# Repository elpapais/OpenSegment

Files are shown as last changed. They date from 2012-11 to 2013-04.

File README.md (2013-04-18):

OpenSegment Serial Display
==========================

[OpenSegment  
*OpenSegment Serial Display (Yellow) (COM-11645)*](https://www.sparkfun.com/products/11645)

OpenSegment is a ATmega328 based backpack for larger 7-segment displays. The ATmega receives data over digital interfaces (such as TWI, UART, SPI and buttons) and does all the PWM and upkeep of the display. 

Larger 7-segment displays pull more power than a microcontroller is able to drive directly. OpenSegment has 8 PNP and 4 NPN transistors in order to drive the segments at their maximum brightness.

**Features:**
* Standard FTDI connection
* Arduino Pro Mini @ 8MHz bootloader
* 5V functionality

This part was created in Eagle 6.3

Repository Contents
-------------------
* **/Hardware** - All Eagle design files and 3D files(.brd, .sch,)
* **/Production** - Test bed files and production panel files
* **Note:** Firmware is not included in this repo. Please see the [Serial7SegmentDisplay repo](https://github.com/sparkfun/Serial7SegmentDisplay) for the firmware. 

Product Versions
----------------
* [COM-11644](https://www.sparkfun.com/products/11644)- Red display
* [COM-11645](https://www.sparkfun.com/products/11645) - Yellow display
* [COM-11646](https://www.sparkfun.com/products/11646) - Green display
* [COM-11647](https://www.sparkfun.com/products/11647) - Blue display
* [COM-11648](https://www.sparkfun.com/products/11648) - White display

License Information
-------------------
The hardware is released under [Creative Commons Share-alike 3.0](http://creativecommons.org/licenses/by-sa/3.0/).

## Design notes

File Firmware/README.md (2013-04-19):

OpenSegment Serial Display Firmware
==========================

The firmware for OpenSegment is located over on the [Serial7Segment repo](https://github.com/sparkfun/Serial7SegmentDisplay/tree/master/firmware/Serial%207-Segment%20Display/Serial_7_Segment_Display_Firmware). We combined the firmware for both Serial7Segment and OpenSegment because it's the same code with different pin assignments (to make the PCB layout easier).

If there are any improvements or modifications you'd like to make to the firmware, please create an issue over on the Serial7Segment [issues page](https://github.com/sparkfun/Serial7SegmentDisplay/issues?state=open).

The firmware for Serial7Segment and OpenSegment are based on the [SevSeg](https://github.com/sparkfun/SevSeg) library for Arduino, written by SparkFun.

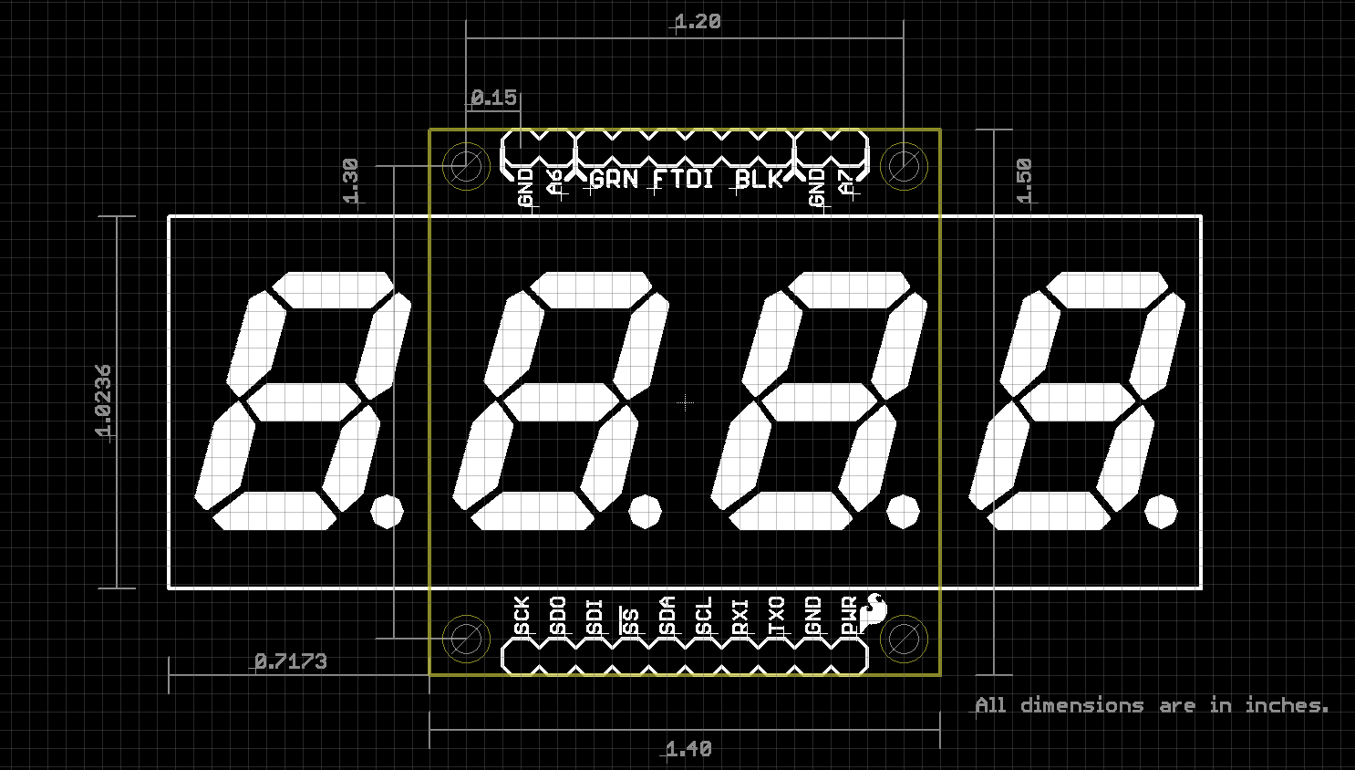
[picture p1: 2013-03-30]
Hardware/OpenSegment-Dimensions-v13.png

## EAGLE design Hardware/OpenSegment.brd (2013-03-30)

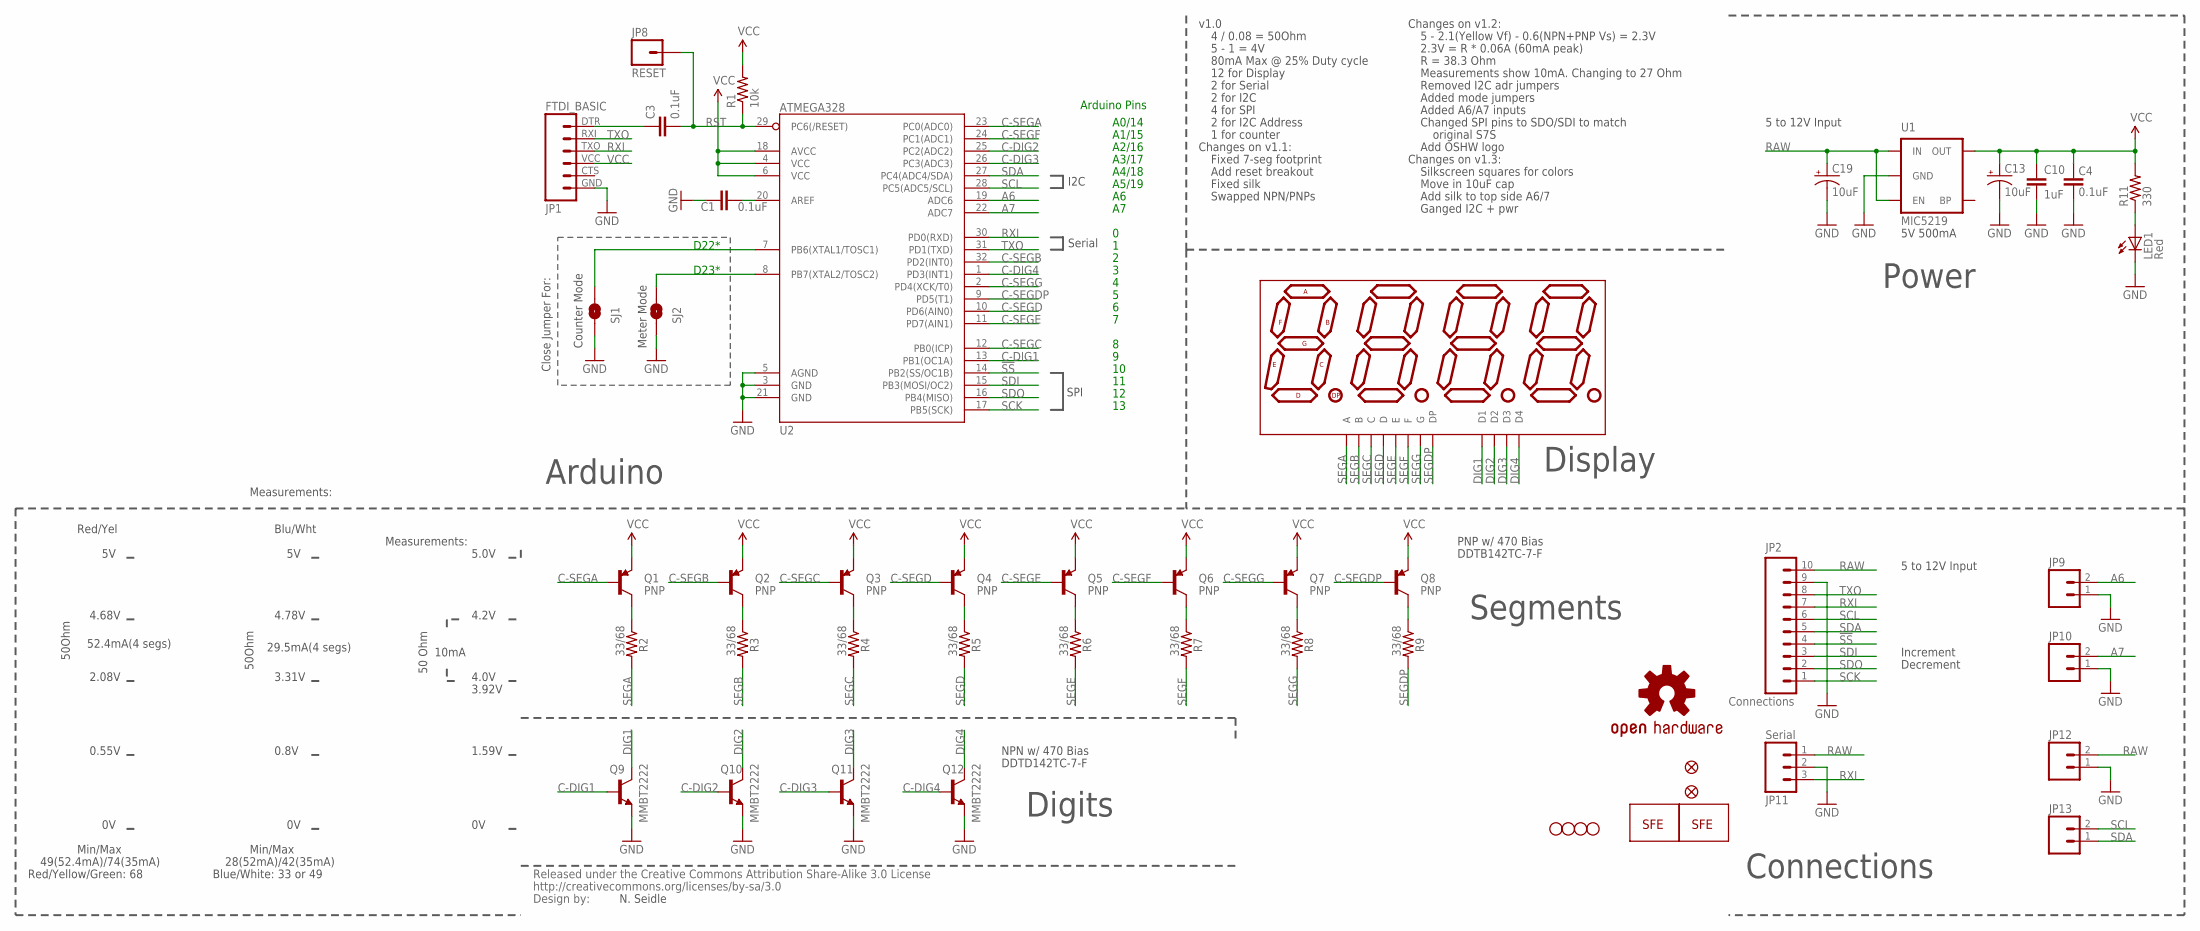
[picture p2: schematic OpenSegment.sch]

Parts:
C1, C3, C4: 0.1uF; 0402-CAP
C10: 1uF; 0402-CAP
C13, C19: 10uF; EIA3216
JP1: FTDI_BASIC
JP2: Connections; 1X10
JP3, JP4, JP5, JP6: STAND-OFF
JP7, JP14: FIDUCIALUFIDUCIAL; MICRO-FIDUCIAL
JP8: RESET; 1X01
JP9, JP10, JP12, JP13: M02PTH; 1X02
JP11: Serial; JST-3-PTH
LED1: Red; LED-0603
Q1, Q2, Q3, Q4, Q5, Q6, Q7, Q8: PNP; SOT23-3
Q9, Q10, Q11, Q12: MMBT2222; SOT23-3
R1: 10k; 0402-RES
R2, R3, R4, R5, R6, R7, R8, R9: 33/68; 0402-RES
R11: 330; 0402-RES
SJ1, SJ2: Counter Ctl; SJ_2S-NO
U1: MIC5219; SOT23-5
U2: ATMEGA328; TQFP32-08
U3: 7-SEGMENT-4DIGIT-COUNTERPTH; 7-SEGMENT-4DIGIT-COUNTER
U$2: LOGO-SFESK; SFE-LOGO-FLAME
U$3: CREATIVE_COMMONS
U$4: OSHW-LOGOS; OSHW-LOGO-S
U$7: LOGO-SFENW2; SFE-NEW-WEB

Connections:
!SS: JP2.4, U2.14 (PB2(SS/OC1B))
A6: JP9.2, U2.19 (ADC6)
A7: JP10.2, U2.22 (ADC7)
ANALOG: SJ2.1, U2.8 (PB7(XTAL2/TOSC2))
C-DIG1: Q9.1 (B), U2.13 (PB1(OC1A))
C-DIG2: Q10.1 (B), U2.25 (PC2(ADC2))
C-DIG3: Q11.1 (B), U2.26 (PC3(ADC3))
C-DIG4: Q12.1 (B), U2.1 (PD3(INT1))
C-SEGA: Q1.1 (B), U2.23 (PC0(ADC0))
C-SEGB: Q2.1 (B), U2.32 (PD2(INT0))
C-SEGC: Q3.1 (B), U2.12 (PB0(ICP))
C-SEGD: Q4.1 (B), U2.10 (PD6(AIN0))
C-SEGDP: Q8.1 (B), U2.9 (PD5(T1))
C-SEGE: Q5.1 (B), U2.11 (PD7(AIN1))
C-SEGF: Q6.1 (B), U2.24 (PC1(ADC1))
C-SEGG: Q7.1 (B), U2.2 (PD4(XCK/T0))
COUNTER: SJ1.1, U2.7 (PB6(XTAL1/TOSC1))
DIG1: Q9.3 (C), U3.12 (D1)
DIG2: Q10.3 (C), U3.9 (D2)
DIG3: Q11.3 (C), U3.8 (D3)
DIG4: Q12.3 (C), U3.6 (D4)
GND: C1.1, C4.1, C10.2, C13.C (-), C19.C (-), JP1.GND (6), JP2.9, JP9.1, JP10.1, JP11.2, JP12.1, LED1.C, Q9.2 (E), Q10.2 (E), Q11.2 (E), Q12.2 (E), SJ1.2, SJ2.2, U1.2 (GND), U2.3 (GND), U2.5 (AGND), U2.21 (GND)
unnamed: Q1.3 (C), R2.1
unnamed: C3.1, JP1.DTR (1)
unnamed: Q2.3 (C), R3.1
unnamed: Q3.3 (C), R4.1
unnamed: Q4.3 (C), R5.1
unnamed: Q5.3 (C), R6.1
unnamed: Q6.3 (C), R7.1
unnamed: Q7.3 (C), R8.1
unnamed: Q8.3 (C), R9.1
unnamed: C1.2, U2.20 (AREF)
unnamed: LED1.A, R11.1
RAW: C19.A (+), JP2.10, JP11.1, JP12.2, U1.1 (IN), U1.3 (EN)
RST: C3.2, JP8.1, R1.1, U2.29 (PC6(/RESET))
RXI: JP1.TXO (3), JP2.7, JP11.3, U2.30 (PD0(RXD))
SCK: JP2.1, U2.17 (PB5(SCK))
SCL: JP2.6, JP13.2, U2.28 (PC5(ADC5/SCL))
SDA: JP2.5, JP13.1, U2.27 (PC4(ADC4/SDA))
SDI: JP2.3, U2.15 (PB3(MOSI/OC2))
SDO: JP2.2, U2.16 (PB4(MISO))
SEGA: R2.2, U3.11 (A)
SEGB: R3.2, U3.7 (B)
SEGC: R4.2, U3.4 (C)
SEGD: R5.2, U3.2 (D)
SEGDP: R9.2, U3.3 (DP)
SEGE: R6.2, U3.1 (E)
SEGF: R7.2, U3.10 (F)
SEGG: R8.2, U3.5 (G)
TXO: JP1.RXI (2), JP2.8, U2.31 (PD1(TXD))
VCC: C4.2, C10.1, C13.A (+), JP1.VCC (4), Q1.2 (E), Q2.2 (E), Q3.2 (E), Q4.2 (E), Q5.2 (E), Q6.2 (E), Q7.2 (E), Q8.2 (E), R1.2, R11.2, U1.5 (OUT), U2.4 (VCC), U2.6 (VCC), U2.18 (AVCC)

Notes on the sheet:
N. Seidle
A0/14
A1/15
A2/16
A3/17
A4/18
A5/19
Arduino Pins
Changes on v1.1:
5V 500mA
5 - 1 = 4V
80mA Max @ 25% Duty cycle
4 / 0.08 = 50Ohm
SPI
12 for Display
1 for counter
2 for I2C
4 for SPI
2 for Serial
v1.0
2 for I2C Address
Serial
I2C
Counter Mode
Arduino
Display
Segments
Digits
Connections
Power
Fixed 7-seg footprint
Add reset breakout
Fixed silk
Swapped NPN/PNPs
D22*
D23*
5 - 2.1(Yellow Vf) - 0.6(NPN+PNP Vs) = 2.3V
2.3V = R * 0.06A (60mA peak)
Changes on v1.2:
4.2V

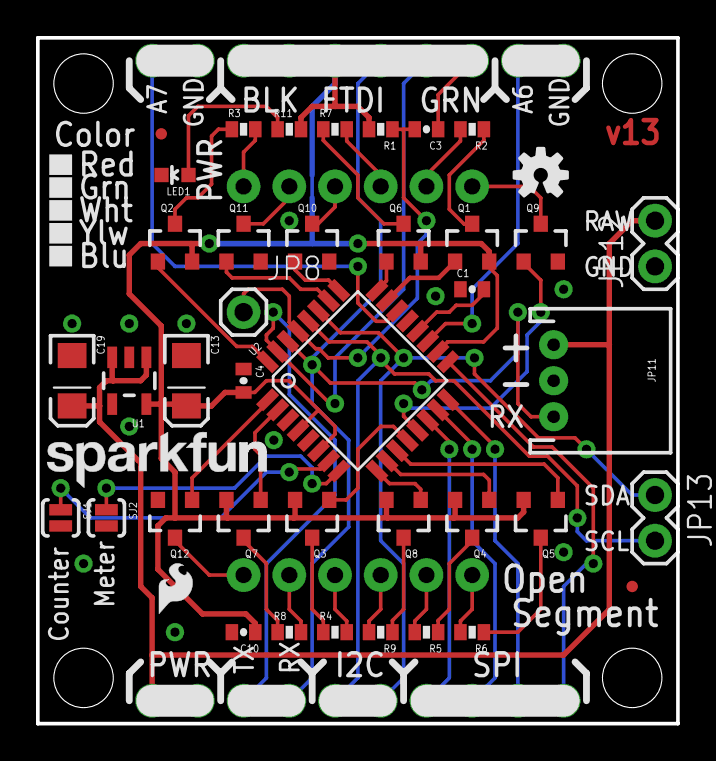
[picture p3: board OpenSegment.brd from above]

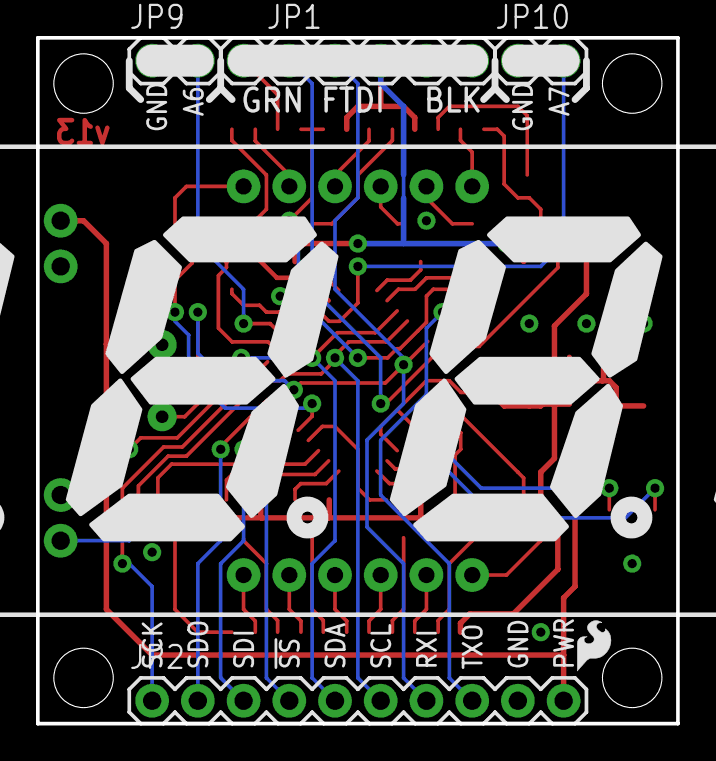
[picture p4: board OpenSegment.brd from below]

Board: 2 copper layers, 35.6 x 38.1 mm, 53 parts (6 on the bottom side), 51 nets.

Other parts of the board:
U$1: LOGO-SFESK; SFE-LOGO-FLAME

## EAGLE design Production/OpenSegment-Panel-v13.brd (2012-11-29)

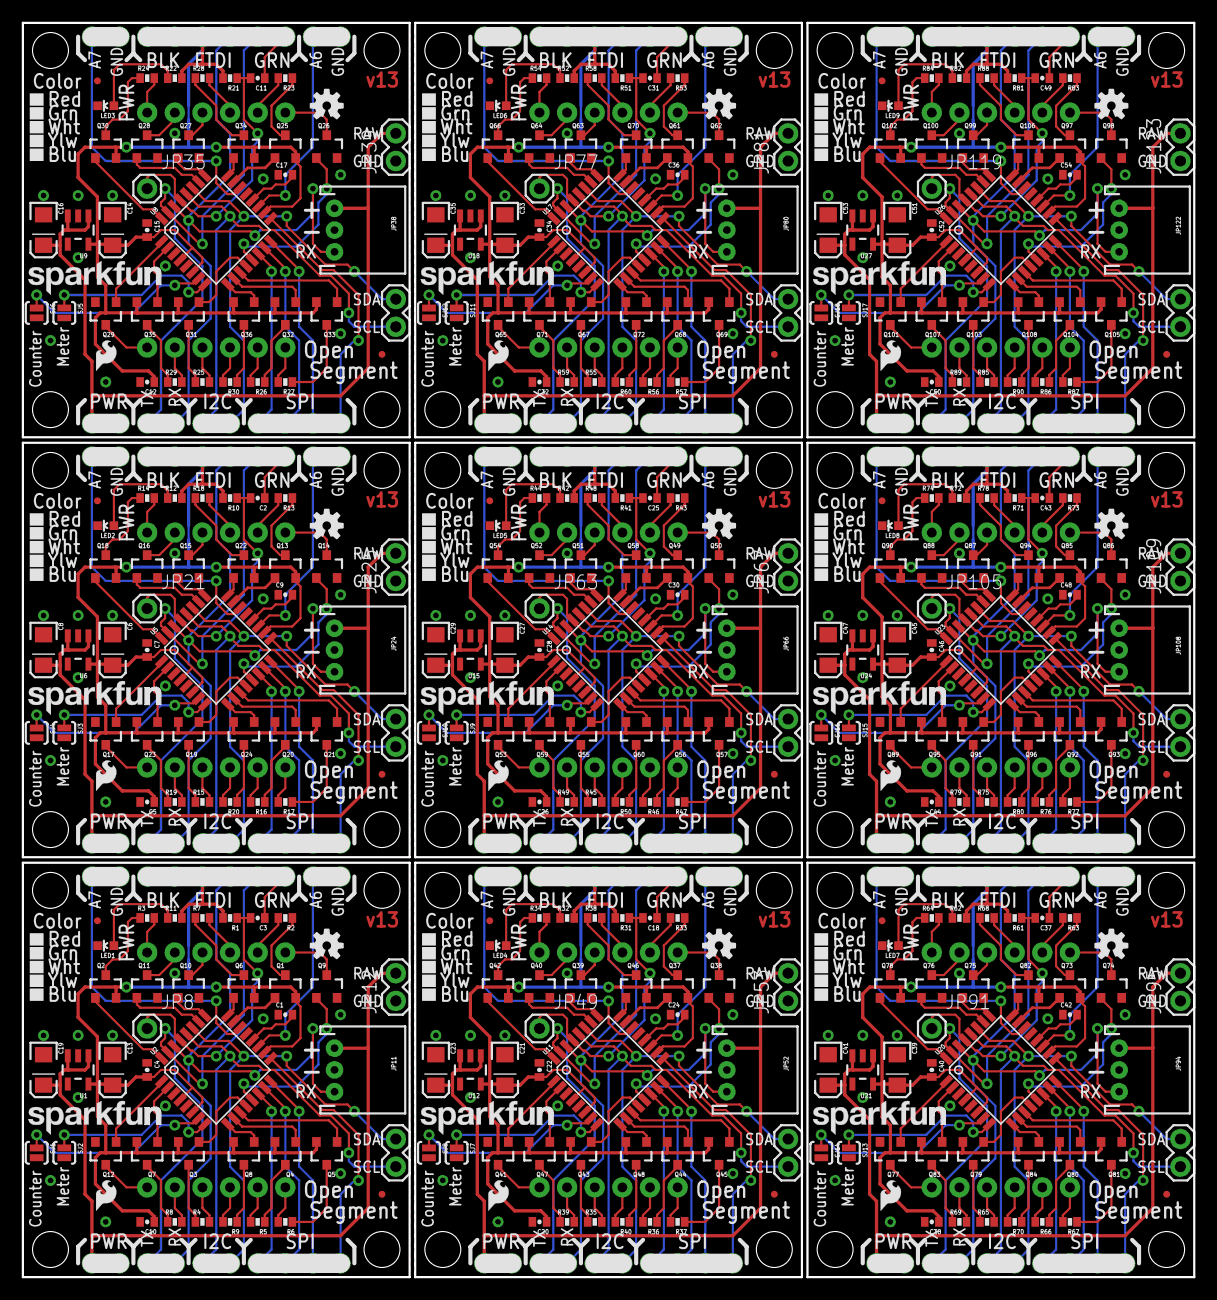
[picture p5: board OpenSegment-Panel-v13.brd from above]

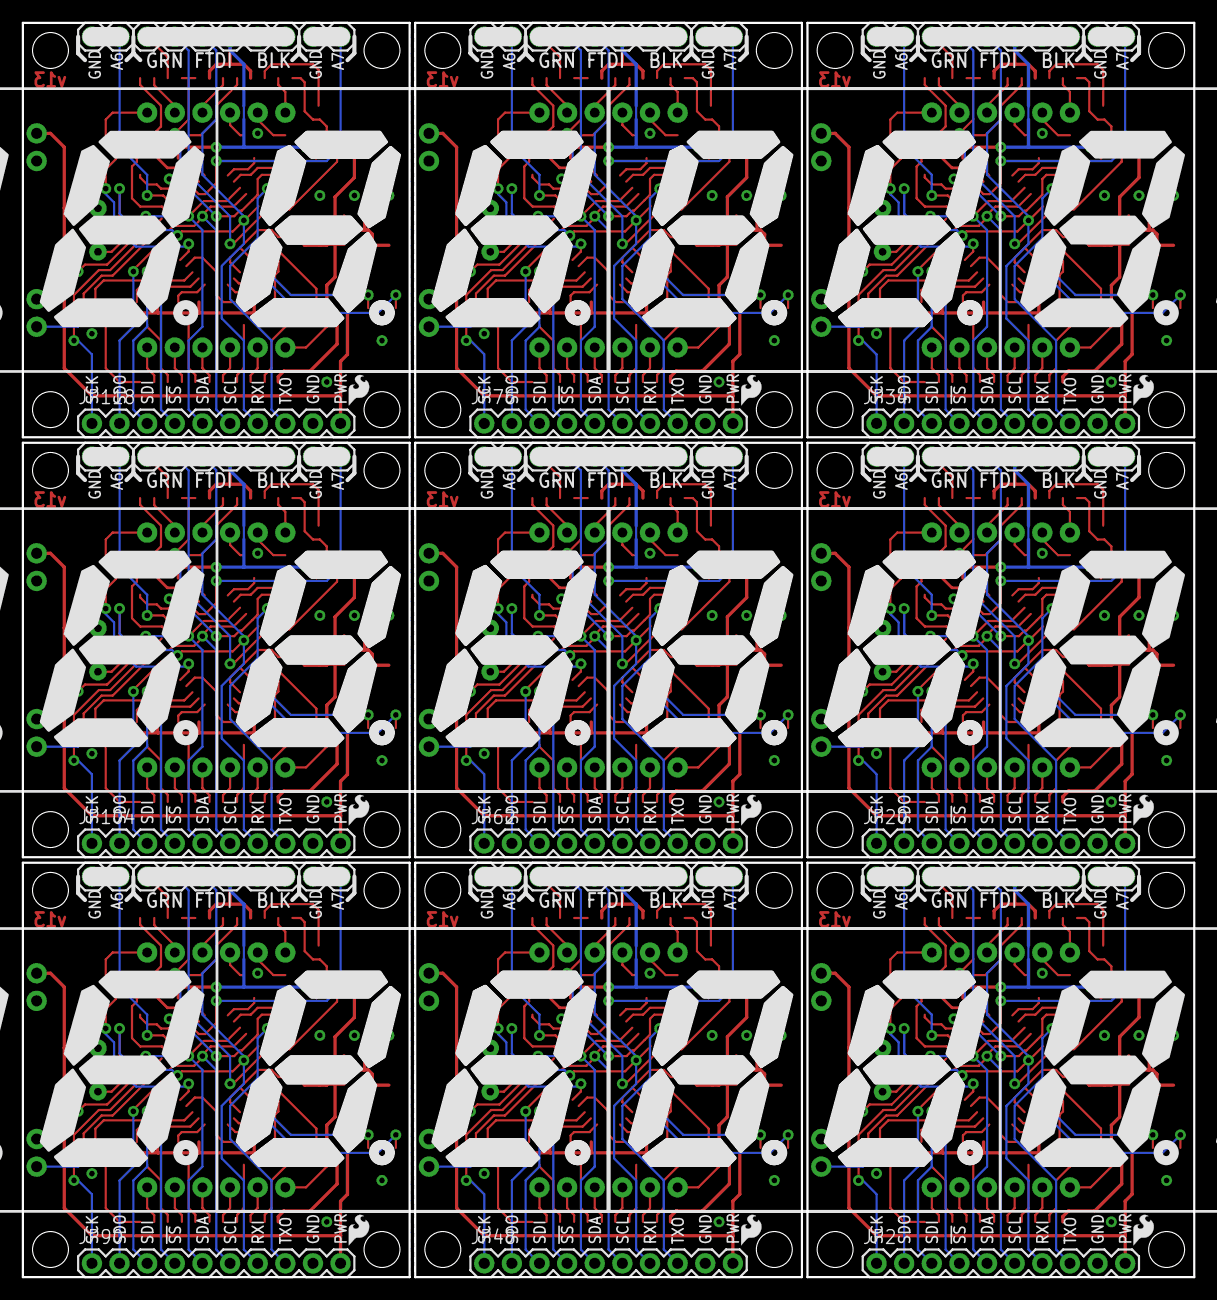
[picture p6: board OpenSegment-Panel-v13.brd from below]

Board: 2 copper layers, 107.7 x 115.3 mm, 468 parts (54 on the bottom side), 459 nets.

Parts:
C1, C2, C3, C4, C7, C9, C11, C15, C17, C18, C22, C24, C25, C28, C30, C31, C34, C36, C37, C40, C42, C43, C46, C48, C49, C52, C54: 0.1uF; 0402-CAP
C5, C10, C12, C20, C26, C32, C38, C44, C50: 1uF; 0402-CAP
C6, C8, C13, C14, C16, C19, C21, C23, C27, C29, C33, C35, C39, C41, C45, C47, C51, C53: 10uF; EIA3216
JP1, JP15, JP29, JP43, JP57, JP71, JP85, JP99, JP113: FTDI_BASIC
JP2, JP20, JP34, JP48, JP62, JP76, JP90, JP104, JP118: Connections; 1X10
JP3, JP4, JP5, JP6, JP16, JP17, JP18, JP19, JP30, JP31, JP32, JP33, JP44, JP45, JP46, JP47, JP58, JP59, JP60, JP61, JP72, JP73, JP74, JP75, JP86, JP87, JP88, JP89, JP100, JP101, JP102, JP103, JP114, JP115, JP116, JP117: STAND-OFF
JP7, JP14, JP27, JP28, JP41, JP42, JP55, JP56, JP69, JP70, JP83, JP84, JP97, JP98, JP111, JP112, JP125, JP126: FIDUCIALUFIDUCIAL; MICRO-FIDUCIAL
JP8, JP21, JP35, JP49, JP63, JP77, JP91, JP105, JP119: RESET; 1X01
JP9, JP10, JP12, JP13, JP22, JP23, JP25, JP26, JP36, JP37, JP39, JP40, JP50, JP51, JP53, JP54, JP64, JP65, JP67, JP68, JP78, JP79, JP81, JP82, JP92, JP93, JP95, JP96, JP106, JP107, JP109, JP110, JP120, JP121, JP123, JP124: 1X02
JP11, JP24, JP38, JP52, JP66, JP80, JP94, JP108, JP122: Serial; JST-3-PTH
LED1, LED2, LED3, LED4, LED5, LED6, LED7, LED8, LED9: Red; LED-0603
Q1, Q2, Q3, Q4, Q5, Q6, Q7, Q8, Q13, Q18, Q19, Q20, Q21, Q22, Q23, Q24, Q25, Q30, Q31, Q32, Q33, Q34, Q35, Q36, Q37, Q42, Q43, Q44, Q45, Q46, Q47, Q48, Q49, Q54, Q55, Q56, Q57, Q58, Q59, Q60, Q61, Q66, Q67, Q68, Q69, Q70, Q71, Q72, Q73, Q78, Q79, Q80, Q81, Q82, Q83, Q84, Q85, Q90, Q91, Q92, Q93, Q94, Q95, Q96, Q97, Q102, Q103, Q104, Q105, Q106, Q107, Q108: PNP; SOT23-3
Q9, Q10, Q11, Q12, Q14, Q15, Q16, Q17, Q26, Q27, Q28, Q29, Q38, Q39, Q40, Q41, Q50, Q51, Q52, Q53, Q62, Q63, Q64, Q65, Q74, Q75, Q76, Q77, Q86, Q87, Q88, Q89, Q98, Q99, Q100, Q101: MMBT2222; SOT23-3
R1, R10, R21, R31, R41, R51, R61, R71, R81: 10k; 0402-RES
R2, R3, R4, R5, R6, R7, R8, R9, R13, R14, R15, R16, R17, R18, R19, R20, R23, R24, R25, R26, R27, R28, R29, R30, R33, R34, R35, R36, R37, R38, R39, R40, R43, R44, R45, R46, R47, R48, R49, R50, R53, R54, R55, R56, R57, R58, R59, R60, R63, R64, R65, R66, R67, R68, R69, R70, R73, R74, R75, R76, R77, R78, R79, R80, R83, R84, R85, R86, R87, R88, R89, R90: 27; 0402-RES
R11, R12, R22, R32, R42, R52, R62, R72, R82: 330; 0402-RES
SJ1, SJ2, SJ3, SJ4, SJ5, SJ6, SJ7, SJ8, SJ9, SJ10, SJ11, SJ12, SJ13, SJ14, SJ15, SJ16, SJ17, SJ18: Counter Ctl; SJ_2S-NO
U1, U6, U9, U12, U15, U18, U21, U24, U27: MIC5219; SOT23-5
U2, U5, U8, U11, U14, U17, U20, U23, U26: ATMEGA328; TQFP32-08
U3, U4, U7, U10, U13, U16, U19, U22, U25: 7-SEGMENT-4DIGIT-COUNTERPTH; 7-SEGMENT-4DIGIT-COUNTER
U$1, U$2, U$5, U$6, U$10, U$11, U$14, U$15, U$18, U$19, U$22, U$23, U$26, U$27, U$30, U$31, U$34, U$35: LOGO-SFESK; SFE-LOGO-FLAME
U$3, U$7, U$9, U$13, U$17, U$21, U$25, U$29, U$33: LOGO-SFENW2; SFE-NEW-WEB
U$4, U$8, U$12, U$16, U$20, U$24, U$28, U$32, U$36: OSHW-LOGOS; OSHW-LOGO-S

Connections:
!SS: JP2.4, U2.14
!SS1: JP20.4, U5.14
!SS2: JP34.4, U8.14
!SS3: JP48.4, U11.14
!SS4: JP62.4, U14.14
!SS5: JP76.4, U17.14
!SS6: JP90.4, U20.14
!SS7: JP104.4, U23.14
!SS8: JP118.4, U26.14
A1: JP22.2, U5.19
A2: JP23.2, U5.22
A3: JP36.2, U8.19
A4: JP37.2, U8.22
A5: JP50.2, U11.19
A6: JP9.2, U2.19
A7: JP10.2, U2.22
A8: JP51.2, U11.22
A9: JP64.2, U14.19
A10: JP65.2, U14.22
A11: JP78.2, U17.19
A12: JP79.2, U17.22
A13: JP92.2, U20.19
A14: JP93.2, U20.22
A15: JP106.2, U23.19
A16: JP107.2, U23.22
A17: JP120.2, U26.19
A18: JP121.2, U26.22
ANALOG: SJ2.1, U2.8
ANALOG1: SJ3.1, U5.8
ANALOG2: SJ5.1, U8.8
ANALOG3: SJ7.1, U11.8
ANALOG4: SJ9.1, U14.8
ANALOG5: SJ11.1, U17.8
ANALOG6: SJ13.1, U20.8
ANALOG7: SJ15.1, U23.8
ANALOG8: SJ17.1, U26.8
C-DIG1: Q9.1, U2.13
C-DIG2: Q10.1, U2.25
C-DIG3: Q11.1, U2.26
C-DIG4: Q12.1, U2.1
C-DIG5: Q14.1, U5.13
C-DIG6: Q15.1, U5.25
C-DIG7: Q16.1, U5.26
C-DIG8: Q17.1, U5.1
C-DIG9: Q26.1, U8.13
C-DIG10: Q27.1, U8.25
C-DIG11: Q28.1, U8.26
C-DIG12: Q29.1, U8.1
C-DIG13: Q38.1, U11.13
C-DIG14: Q39.1, U11.25
C-DIG15: Q40.1, U11.26
C-DIG16: Q41.1, U11.1
C-DIG17: Q50.1, U14.13
C-DIG18: Q51.1, U14.25
C-DIG19: Q52.1, U14.26
C-DIG20: Q53.1, U14.1
C-DIG21: Q62.1, U17.13
C-DIG22: Q63.1, U17.25
C-DIG23: Q64.1, U17.26
C-DIG24: Q65.1, U17.1
C-DIG25: Q74.1, U20.13
C-DIG26: Q75.1, U20.25
C-DIG27: Q76.1, U20.26
C-DIG28: Q77.1, U20.1
C-DIG29: Q86.1, U23.13
C-DIG30: Q87.1, U23.25
C-DIG31: Q88.1, U23.26
C-DIG32: Q89.1, U23.1
C-DIG33: Q98.1, U26.13
C-DIG34: Q99.1, U26.25
C-DIG35: Q100.1, U26.26
C-DIG36: Q101.1, U26.1
C-SEGA: Q1.1, U2.23
C-SEGA1: Q13.1, U5.23
C-SEGA2: Q25.1, U8.23
C-SEGA3: Q37.1, U11.23
C-SEGA4: Q49.1, U14.23
C-SEGA5: Q61.1, U17.23
C-SEGA6: Q73.1, U20.23
C-SEGA7: Q85.1, U23.23
C-SEGA8: Q97.1, U26.23
C-SEGB: Q2.1, U2.32
C-SEGB1: Q18.1, U5.32
C-SEGB2: Q30.1, U8.32
C-SEGB3: Q42.1, U11.32
C-SEGB4: Q54.1, U14.32
C-SEGB5: Q66.1, U17.32
C-SEGB6: Q78.1, U20.32
C-SEGB7: Q90.1, U23.32
C-SEGB8: Q102.1, U26.32
C-SEGC: Q3.1, U2.12
C-SEGC1: Q19.1, U5.12
C-SEGC2: Q31.1, U8.12
C-SEGC3: Q43.1, U11.12
C-SEGC4: Q55.1, U14.12
C-SEGC5: Q67.1, U17.12
C-SEGC6: Q79.1, U20.12
C-SEGC7: Q91.1, U23.12
C-SEGC8: Q103.1, U26.12
C-SEGD: Q4.1, U2.10
C-SEGD1: Q20.1, U5.10
C-SEGD2: Q32.1, U8.10
C-SEGD3: Q44.1, U11.10
C-SEGD4: Q56.1, U14.10
C-SEGD5: Q68.1, U17.10
C-SEGD6: Q80.1, U20.10
C-SEGD7: Q92.1, U23.10
C-SEGD8: Q104.1, U26.10
C-SEGDP: Q8.1, U2.9
C-SEGDP1: Q24.1, U5.9
C-SEGDP2: Q36.1, U8.9
C-SEGDP3: Q48.1, U11.9
C-SEGDP4: Q60.1, U14.9
C-SEGDP5: Q72.1, U17.9
C-SEGDP6: Q84.1, U20.9
C-SEGDP7: Q96.1, U23.9
C-SEGDP8: Q108.1, U26.9
C-SEGE: Q5.1, U2.11
C-SEGE1: Q21.1, U5.11
C-SEGE2: Q33.1, U8.11
C-SEGE3: Q45.1, U11.11
C-SEGE4: Q57.1, U14.11
C-SEGE5: Q69.1, U17.11
C-SEGE6: Q81.1, U20.11
C-SEGE7: Q93.1, U23.11
C-SEGE8: Q105.1, U26.11
C-SEGF: Q6.1, U2.24
C-SEGF1: Q22.1, U5.24
C-SEGF2: Q34.1, U8.24
C-SEGF3: Q46.1, U11.24
C-SEGF4: Q58.1, U14.24
C-SEGF5: Q70.1, U17.24
C-SEGF6: Q82.1, U20.24
C-SEGF7: Q94.1, U23.24
C-SEGF8: Q106.1, U26.24
C-SEGG: Q7.1, U2.2
C-SEGG1: Q23.1, U5.2
C-SEGG2: Q35.1, U8.2
C-SEGG3: Q47.1, U11.2
C-SEGG4: Q59.1, U14.2
C-SEGG5: Q71.1, U17.2
C-SEGG6: Q83.1, U20.2
C-SEGG7: Q95.1, U23.2
C-SEGG8: Q107.1, U26.2
COUNTER: SJ1.1, U2.7
COUNTER1: SJ4.1, U5.7
COUNTER2: SJ6.1, U8.7
COUNTER3: SJ8.1, U11.7
COUNTER4: SJ10.1, U14.7
COUNTER5: SJ12.1, U17.7
COUNTER6: SJ14.1, U20.7
COUNTER7: SJ16.1, U23.7
COUNTER8: SJ18.1, U26.7
DIG1: Q9.3, U3.12
DIG2: Q10.3, U3.9
DIG3: Q11.3, U3.8
DIG4: Q12.3, U3.6
DIG5: Q14.3, U4.12
DIG6: Q15.3, U4.9
DIG7: Q16.3, U4.8
DIG8: Q17.3, U4.6
DIG9: Q26.3, U7.12
DIG10: Q27.3, U7.9
DIG11: Q28.3, U7.8
DIG12: Q29.3, U7.6
DIG13: Q38.3, U10.12
DIG14: Q39.3, U10.9
DIG15: Q40.3, U10.8
DIG16: Q41.3, U10.6
DIG17: Q50.3, U13.12
DIG18: Q51.3, U13.9
DIG19: Q52.3, U13.8
DIG20: Q53.3, U13.6
DIG21: Q62.3, U16.12
DIG22: Q63.3, U16.9
DIG23: Q64.3, U16.8
DIG24: Q65.3, U16.6
DIG25: Q74.3, U19.12
DIG26: Q75.3, U19.9
DIG27: Q76.3, U19.8
DIG28: Q77.3, U19.6
DIG29: Q86.3, U22.12
DIG30: Q87.3, U22.9
DIG31: Q88.3, U22.8
DIG32: Q89.3, U22.6
DIG33: Q98.3, U25.12
DIG34: Q99.3, U25.9
DIG35: Q100.3, U25.8
DIG36: Q101.3, U25.6
GND: C1.1, C4.1, C10.2, C13.C, C19.C, JP1.GND, JP2.9, JP9.1, JP10.1, JP11.2, JP12.1, LED1.C, Q9.2, Q10.2, Q11.2, Q12.2, SJ1.2, SJ2.2, U1.2, U2.3, U2.5, U2.21
GND1: C5.2, C6.C, C7.1, C8.C, C9.1, JP15.GND, JP20.9, JP22.1, JP23.1, JP24.2, JP25.1, LED2.C, Q14.2, Q15.2, Q16.2, Q17.2, SJ3.2, SJ4.2, U5.3, U5.5, U5.21, U6.2
GND2: C12.2, C14.C, C15.1, C16.C, C17.1, JP29.GND, JP34.9, JP36.1, JP37.1, JP38.2, JP39.1, LED3.C, Q26.2, Q27.2, Q28.2, Q29.2, SJ5.2, SJ6.2, U8.3, U8.5, U8.21, U9.2
GND3: C20.2, C21.C, C22.1, C23.C, C24.1, JP43.GND, JP48.9, JP50.1, JP51.1, JP52.2, JP53.1, LED4.C, Q38.2, Q39.2, Q40.2, Q41.2, SJ7.2, SJ8.2, U11.3, U11.5, U11.21, U12.2
GND4: C26.2, C27.C, C28.1, C29.C, C30.1, JP57.GND, JP62.9, JP64.1, JP65.1, JP66.2, JP67.1, LED5.C, Q50.2, Q51.2, Q52.2, Q53.2, SJ9.2, SJ10.2, U14.3, U14.5, U14.21, U15.2
GND5: C32.2, C33.C, C34.1, C35.C, C36.1, JP71.GND, JP76.9, JP78.1, JP79.1, JP80.2, JP81.1, LED6.C, Q62.2, Q63.2, Q64.2, Q65.2, SJ11.2, SJ12.2, U17.3, U17.5, U17.21, U18.2
GND6: C38.2, C39.C, C40.1, C41.C, C42.1, JP85.GND, JP90.9, JP92.1, JP93.1, JP94.2, JP95.1, LED7.C, Q74.2, Q75.2, Q76.2, Q77.2, SJ13.2, SJ14.2, U20.3, U20.5, U20.21, U21.2
GND7: C44.2, C45.C, C46.1, C47.C, C48.1, JP99.GND, JP104.9, JP106.1, JP107.1, JP108.2, JP109.1, LED8.C, Q86.2, Q87.2, Q88.2, Q89.2, SJ15.2, SJ16.2, U23.3, U23.5, U23.21, U24.2
GND8: C50.2, C51.C, C52.1, C53.C, C54.1, JP113.GND, JP118.9, JP120.1, JP121.1, JP122.2, JP123.1, LED9.C, Q98.2, Q99.2, Q100.2, Q101.2, SJ17.2, SJ18.2, U26.3, U26.5, U26.21, U27.2
unnamed: Q1.3, R2.1
unnamed: C2.1, JP15.DTR
unnamed: C3.1, JP1.DTR
unnamed: Q2.3, R3.1
unnamed: Q3.3, R4.1
unnamed: Q4.3, R5.1
unnamed: Q5.3, R6.1
unnamed: Q6.3, R7.1
unnamed: Q7.3, R8.1
unnamed: Q8.3, R9.1
unnamed: C1.2, U2.20
unnamed: LED2.A, R12.1
unnamed: Q13.3, R13.1
unnamed: Q18.3, R14.1
unnamed: Q19.3, R15.1
unnamed: Q20.3, R16.1
unnamed: Q21.3, R17.1
unnamed: Q22.3, R18.1
unnamed: Q23.3, R19.1
unnamed: Q24.3, R20.1
unnamed: C9.2, U5.20
unnamed: C11.1, JP29.DTR
unnamed: LED3.A, R22.1
unnamed: Q25.3, R23.1
unnamed: Q30.3, R24.1
unnamed: Q31.3, R25.1
unnamed: Q32.3, R26.1
unnamed: Q33.3, R27.1
unnamed: Q34.3, R28.1
unnamed: Q35.3, R29.1
unnamed: Q36.3, R30.1
unnamed: C17.2, U8.20
unnamed: C18.1, JP43.DTR
unnamed: LED4.A, R32.1
unnamed: Q37.3, R33.1
unnamed: Q42.3, R34.1
unnamed: Q43.3, R35.1
unnamed: LED1.A, R11.1
unnamed: Q44.3, R36.1
unnamed: Q45.3, R37.1
unnamed: Q46.3, R38.1
unnamed: Q47.3, R39.1
unnamed: Q48.3, R40.1
unnamed: C24.2, U11.20
unnamed: C25.1, JP57.DTR
unnamed: LED5.A, R42.1
unnamed: Q49.3, R43.1
unnamed: Q54.3, R44.1
unnamed: Q55.3, R45.1
unnamed: Q56.3, R46.1
unnamed: Q57.3, R47.1
unnamed: Q58.3, R48.1
unnamed: Q59.3, R49.1
unnamed: Q60.3, R50.1
unnamed: C30.2, U14.20
unnamed: C31.1, JP71.DTR
unnamed: LED6.A, R52.1
unnamed: Q61.3, R53.1
unnamed: Q66.3, R54.1
unnamed: Q67.3, R55.1
unnamed: Q68.3, R56.1
unnamed: Q69.3, R57.1
unnamed: Q70.3, R58.1
unnamed: Q71.3, R59.1
unnamed: Q72.3, R60.1
unnamed: C36.2, U17.20
unnamed: C37.1, JP85.DTR
unnamed: LED7.A, R62.1
unnamed: Q73.3, R63.1
unnamed: Q78.3, R64.1
unnamed: Q79.3, R65.1
unnamed: Q80.3, R66.1
unnamed: Q81.3, R67.1
unnamed: Q82.3, R68.1
unnamed: Q83.3, R69.1
unnamed: Q84.3, R70.1
unnamed: C42.2, U20.20
unnamed: C43.1, JP99.DTR
unnamed: LED8.A, R72.1
unnamed: Q85.3, R73.1
unnamed: Q90.3, R74.1
unnamed: Q91.3, R75.1
unnamed: Q92.3, R76.1
unnamed: Q93.3, R77.1
unnamed: Q94.3, R78.1
unnamed: Q95.3, R79.1
unnamed: Q96.3, R80.1
unnamed: C48.2, U23.20
unnamed: C49.1, JP113.DTR
unnamed: LED9.A, R82.1
unnamed: Q97.3, R83.1
unnamed: Q102.3, R84.1
unnamed: Q103.3, R85.1
unnamed: Q104.3, R86.1
unnamed: Q105.3, R87.1
unnamed: Q106.3, R88.1
unnamed: Q107.3, R89.1
unnamed: Q108.3, R90.1
unnamed: C54.2, U26.20
RAW: C19.A, JP2.10, JP11.1, JP12.2, U1.1, U1.3
RAW1: C8.A, JP20.10, JP24.1, JP25.2, U6.1, U6.3
RAW2: C16.A, JP34.10, JP38.1, JP39.2, U9.1, U9.3
RAW3: C23.A, JP48.10, JP52.1, JP53.2, U12.1, U12.3
RAW4: C29.A, JP62.10, JP66.1, JP67.2, U15.1, U15.3
RAW5: C35.A, JP76.10, JP80.1, JP81.2, U18.1, U18.3
RAW6: C41.A, JP90.10, JP94.1, JP95.2, U21.1, U21.3
RAW7: C47.A, JP104.10, JP108.1, JP109.2, U24.1, U24.3
RAW8: C53.A, JP118.10, JP122.1, JP123.2, U27.1, U27.3
RST: C3.2, JP8.1, R1.1, U2.29
RST1: C2.2, JP21.1, R10.1, U5.29
RST2: C11.2, JP35.1, R21.1, U8.29
RST3: C18.2, JP49.1, R31.1, U11.29
RST4: C25.2, JP63.1, R41.1, U14.29
RST5: C31.2, JP77.1, R51.1, U17.29
RST6: C37.2, JP91.1, R61.1, U20.29
RST7: C43.2, JP105.1, R71.1, U23.29
RST8: C49.2, JP119.1, R81.1, U26.29
RXI: JP1.TXO, JP2.7, JP11.3, U2.30
RXI1: JP15.TXO, JP20.7, JP24.3, U5.30
RXI2: JP29.TXO, JP34.7, JP38.3, U8.30
RXI3: JP43.TXO, JP48.7, JP52.3, U11.30
RXI4: JP57.TXO, JP62.7, JP66.3, U14.30
RXI5: JP71.TXO, JP76.7, JP80.3, U17.30
RXI6: JP85.TXO, JP90.7, JP94.3, U20.30
RXI7: JP99.TXO, JP104.7, JP108.3, U23.30
RXI8: JP113.TXO, JP118.7, JP122.3, U26.30
SCK: JP2.1, U2.17
SCK1: JP20.1, U5.17
SCK2: JP34.1, U8.17
SCK3: JP48.1, U11.17
SCK4: JP62.1, U14.17
SCK5: JP76.1, U17.17
SCK6: JP90.1, U20.17
SCK7: JP104.1, U23.17
SCK8: JP118.1, U26.17
SCL: JP2.6, JP13.2, U2.28
SCL1: JP20.6, JP26.2, U5.28
SCL2: JP34.6, JP40.2, U8.28
SCL3: JP48.6, JP54.2, U11.28
SCL4: JP62.6, JP68.2, U14.28
SCL5: JP76.6, JP82.2, U17.28
SCL6: JP90.6, JP96.2, U20.28
SCL7: JP104.6, JP110.2, U23.28
SCL8: JP118.6, JP124.2, U26.28
SDA: JP2.5, JP13.1, U2.27
SDA1: JP20.5, JP26.1, U5.27
SDA2: JP34.5, JP40.1, U8.27
SDA3: JP48.5, JP54.1, U11.27
SDA4: JP62.5, JP68.1, U14.27
SDA5: JP76.5, JP82.1, U17.27
SDA6: JP90.5, JP96.1, U20.27
SDA7: JP104.5, JP110.1, U23.27
SDA8: JP118.5, JP124.1, U26.27
SDI: JP2.3, U2.15
SDI1: JP20.3, U5.15
SDI2: JP34.3, U8.15
SDI3: JP48.3, U11.15
SDI4: JP62.3, U14.15
SDI5: JP76.3, U17.15
SDI6: JP90.3, U20.15
SDI7: JP104.3, U23.15
SDI8: JP118.3, U26.15
SDO: JP2.2, U2.16
SDO1: JP20.2, U5.16
SDO2: JP34.2, U8.16
SDO3: JP48.2, U11.16
SDO4: JP62.2, U14.16
SDO5: JP76.2, U17.16
SDO6: JP90.2, U20.16
SDO7: JP104.2, U23.16
SDO8: JP118.2, U26.16
SEGA: R2.2, U3.11
SEGA1: R13.2, U4.11
SEGA2: R23.2, U7.11
SEGA3: R33.2, U10.11
SEGA4: R43.2, U13.11
SEGA5: R53.2, U16.11
SEGA6: R63.2, U19.11
SEGA7: R73.2, U22.11
SEGA8: R83.2, U25.11
SEGB: R3.2, U3.7
SEGB1: R14.2, U4.7
SEGB2: R24.2, U7.7
SEGB3: R34.2, U10.7
SEGB4: R44.2, U13.7
SEGB5: R54.2, U16.7
SEGB6: R64.2, U19.7
SEGB7: R74.2, U22.7
SEGB8: R84.2, U25.7
SEGC: R4.2, U3.4
SEGC1: R15.2, U4.4
SEGC2: R25.2, U7.4
SEGC3: R35.2, U10.4
SEGC4: R45.2, U13.4
SEGC5: R55.2, U16.4
SEGC6: R65.2, U19.4
SEGC7: R75.2, U22.4
SEGC8: R85.2, U25.4
SEGD: R5.2, U3.2
SEGD1: R16.2, U4.2
SEGD2: R26.2, U7.2
SEGD3: R36.2, U10.2
SEGD4: R46.2, U13.2
SEGD5: R56.2, U16.2
SEGD6: R66.2, U19.2
SEGD7: R76.2, U22.2
SEGD8: R86.2, U25.2
SEGDP: R9.2, U3.3
SEGDP1: R20.2, U4.3
SEGDP2: R30.2, U7.3
SEGDP3: R40.2, U10.3
SEGDP4: R50.2, U13.3
SEGDP5: R60.2, U16.3
SEGDP6: R70.2, U19.3
SEGDP7: R80.2, U22.3
SEGDP8: R90.2, U25.3
SEGE: R6.2, U3.1
SEGE1: R17.2, U4.1
SEGE2: R27.2, U7.1
SEGE3: R37.2, U10.1
SEGE4: R47.2, U13.1
SEGE5: R57.2, U16.1
SEGE6: R67.2, U19.1
SEGE7: R77.2, U22.1
SEGE8: R87.2, U25.1
SEGF: R7.2, U3.10
SEGF1: R18.2, U4.10
SEGF2: R28.2, U7.10
SEGF3: R38.2, U10.10
SEGF4: R48.2, U13.10
SEGF5: R58.2, U16.10
SEGF6: R68.2, U19.10
SEGF7: R78.2, U22.10
SEGF8: R88.2, U25.10
SEGG: R8.2, U3.5
SEGG1: R19.2, U4.5
SEGG2: R29.2, U7.5
SEGG3: R39.2, U10.5
SEGG4: R49.2, U13.5
SEGG5: R59.2, U16.5
SEGG6: R69.2, U19.5
SEGG7: R79.2, U22.5
SEGG8: R89.2, U25.5
TXO: JP1.RXI, JP2.8, U2.31
TXO1: JP15.RXI, JP20.8, U5.31
TXO2: JP29.RXI, JP34.8, U8.31
TXO3: JP43.RXI, JP48.8, U11.31
TXO4: JP57.RXI, JP62.8, U14.31
TXO5: JP71.RXI, JP76.8, U17.31
TXO6: JP85.RXI, JP90.8, U20.31
TXO7: JP99.RXI, JP104.8, U23.31
TXO8: JP113.RXI, JP118.8, U26.31
VCC: C4.2, C10.1, C13.A, JP1.VCC, Q1.2, Q2.2, Q3.2, Q4.2, Q5.2, Q6.2, Q7.2, Q8.2, R1.2, R11.2, U1.5, U2.4, U2.6, U2.18
VCC1: C5.1, C6.A, C7.2, JP15.VCC, Q13.2, Q18.2, Q19.2, Q20.2, Q21.2, Q22.2, Q23.2, Q24.2, R10.2, R12.2, U5.4, U5.6, U5.18, U6.5
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

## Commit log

2012-09-23 Original commit
    The original commit includes v1.0 that was laid out for common anode but
    the display we received was common cathode. Version 1.1 of the PCB
    layout works with common cathode.
    The code is very preliminary. We can get data back and forth using I2C
    pretty well. Eventually I need to get this connected with the updated
    version of SevSeg.
    [OpenSegment-v10.brd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]
2012-09-24 Fixed a rare case where a user could try to set the brightness to 10 which would cause a frame reset instead of setting the brightness.
2012-09-25 Fixed the problem where zeros within a number are not printed. Now works well.
2012-09-25 Added very incomplete SPI example and checkEmergenecyReset function.
2012-09-26 Initial testing of SPI interace.
    SPI works with some small delays (1 microsecond). Trying to reduce
    overhead even more.
2012-11-05 Changing v1.2 of the PCB.
    Dropped I2C jumpers. Added analog pins. Thinking about added mode select
    jumpers.
    [OpenSegment-v11.sch, OpenSegment-v12.brd, OpenSegment-v12.sch]
2012-11-24 Added analog, fixed RX connector, many others.
    Changed limiting resistors to 27 Ohm for greater brightness. Renamed SPI
    pins to SDO/SDI. Added mode jumpers. Added OSHW logo. Fixed 3-pin
    connector pinout.
2012-11-28 Added I2C gang pins, silk color squares, adjusted 10uF cap spot.
    [OpenSegment-v12.sch, OpenSegment-v13.brd, OpenSegment-v13.sch]
2012-11-29 Added fiducial markings and created panel
    preparing for mass production
    [OpenSegment-Panel-v13.brd, OpenSegment-v13.brd, OpenSegment-v13.sch]
2013-01-10 Added part #s for transistors and resistor calculations.
    The bias resistors on the NPN and PNPs helped. Reducing current through
    segments further to hit 10-12mA per segment when on for 25% duty cycle.
    Also added calculations for different color displays.
    [OpenSegment-v13.brd, OpenSegment-v13.sch]
2013-01-10 Updated resistor values.
    [OpenSegment-v13.brd, OpenSegment-v13.sch]
2013-03-30 Added dimensions to layout and dimension image.
    [OpenSegment-v13.brd]
2013-04-18 Repo structure cleanup and README update
    [OpenSegment-Panel-v13.brd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]
2013-04-19 Added firmware readme.
    Because this device has firmware, I wanted to point people to the
    location of the firmware.

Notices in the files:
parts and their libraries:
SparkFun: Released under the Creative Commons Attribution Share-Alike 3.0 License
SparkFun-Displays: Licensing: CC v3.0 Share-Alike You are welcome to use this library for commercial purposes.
